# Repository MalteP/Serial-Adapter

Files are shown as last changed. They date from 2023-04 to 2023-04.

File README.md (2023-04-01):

# Serial Adapter

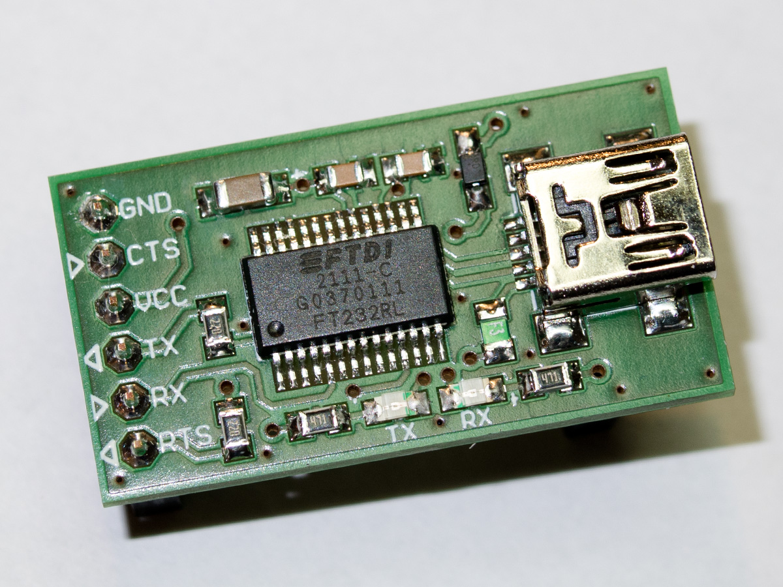
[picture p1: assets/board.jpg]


This is a modified version of the famous [Adafruit FTDI Friend](http://www.adafruit.com/products/284), which has the advantage that you can change the signal and power lines separately to be either 3.3V or 5V.

For short circuit protection a PTC fuse (200mA, 0805 package) has been added. There is also a schottky diode (SOD-323 package) in the VCC output path, protecting the USB port from reverse current flow. (Target powered while computer switched off)

It has become a very useful tool during software development on my [DIY Moteino R6](https://lowpowerlab.com/guide/diy-moteino/). While there is also an open sourced [FTDI Adapter](https://github.com/LowPowerLab/FTDIAdapter) board, it lacks of the features mentioned above when compared to the commercial revision R3.

Parts used:
- Fuse F1: 0ZCK0020FF2G (Mouser), FSMD020-0805-R (Reichelt) or equivalent
- Schottky Diode D1: CUS10F30 (Mouser), NSR0320MW2T1G (Reichelt, Mouser) or equivalent

Links:
- [Schematic (PDF)](ftdifriendsch.pdf)
- [Circuit board (Aisler)](https://aisler.net/p/BZEBBFWU)

### License

Adafruit invests time and resources providing this open source design, please support Adafruit and open-source hardware by purchasing products from [Adafruit](https://www.adafruit.com)!

Designed by Limor Fried/Ladyada for Adafruit Industries.

Creative Commons Attribution/Share-Alike, all text above must be included in any redistribution. See license.txt for additional details.

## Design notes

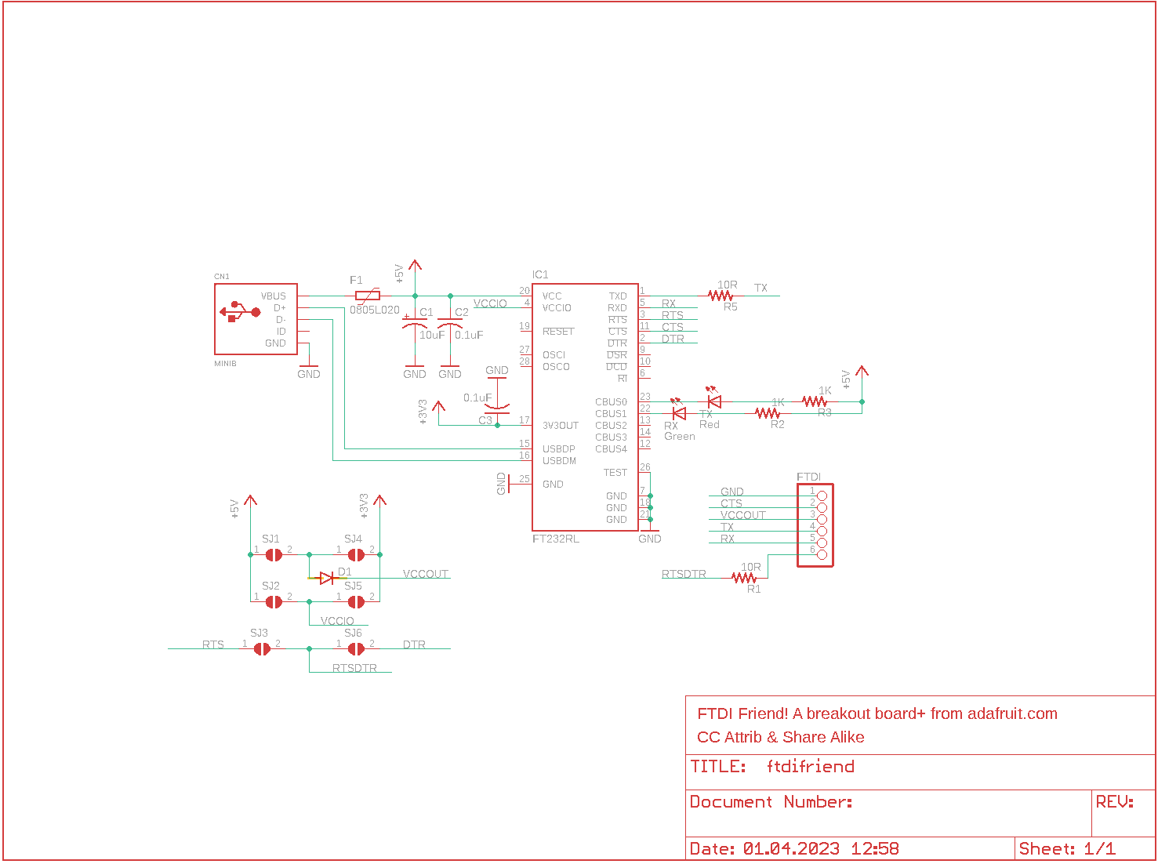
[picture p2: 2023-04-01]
ftdifriendsch.png

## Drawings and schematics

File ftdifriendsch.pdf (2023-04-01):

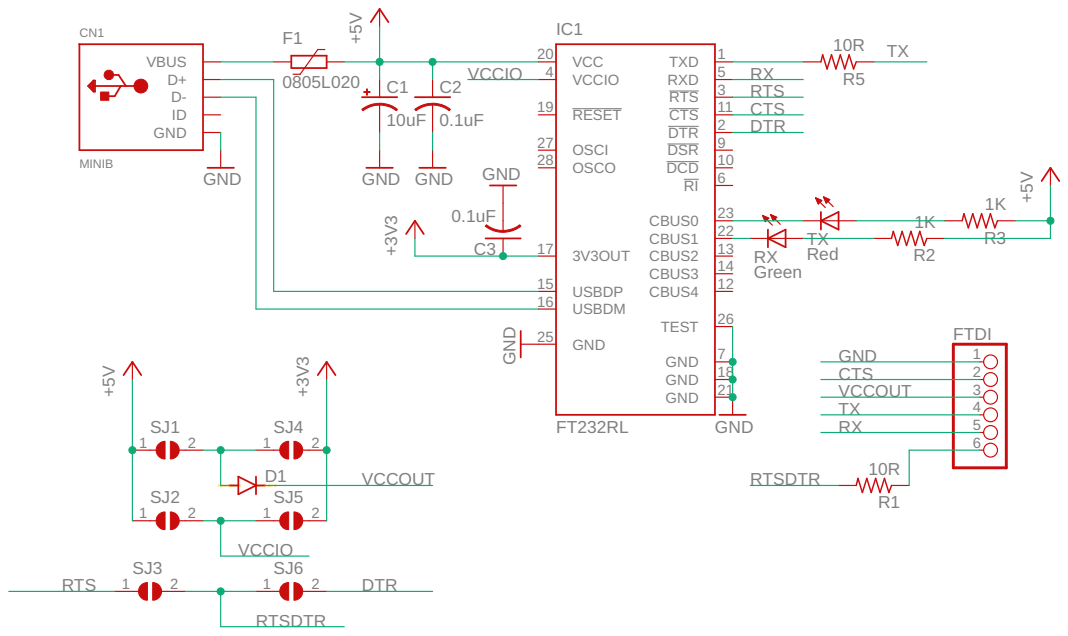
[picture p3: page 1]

FTDI Friend! A breakout board+ from adafruit.com
CC Attrib & Share Alike

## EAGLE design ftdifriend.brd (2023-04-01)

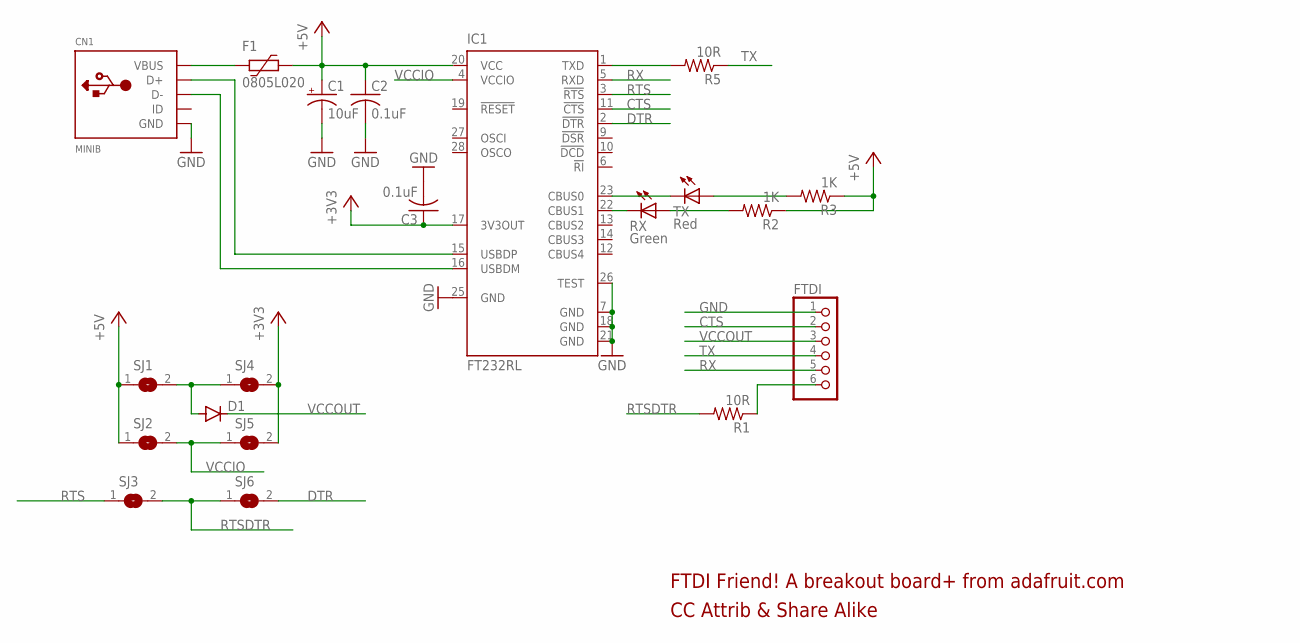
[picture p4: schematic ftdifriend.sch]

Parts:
C1: 10uF; A/3216-18R
C2, C3: 0.1uF; C0805K
CN1: MINIB; USB-MINIB
D1: CUS10F30; SOD323-W
F1: 0805L020; 0805L
FTDI: PINHD-1X6CB; 1X06-CLEANBIG
IC1: FT232RL; SSOP28
R1, R5: 10R; R0805
R2, R3: 1K; R0805
RX: Green; CHIP-LED0805
SJ1, SJ2, SJ3, SJ4, SJ5, SJ6: SJ
TX: Red; CHIP-LED0805

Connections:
+3V3: C3.1, IC1.17 (3V3OUT), SJ4.2, SJ5.2
+5V: C1.+, C2.1, F1.1, IC1.20 (VCC), R2.1, R3.1, SJ1.1, SJ2.1
CTS: FTDI.2, IC1.11 (!CTS)
D+: CN1.D+, IC1.15 (USBDP)
D-: CN1.D-, IC1.16 (USBDM)
DTR: IC1.2 (!DTR), SJ6.2
GND: C1.-, C2.2, C3.2, CN1.GND, FTDI.1, IC1.7 (GND), IC1.18 (GND), IC1.21 (GND), IC1.25 (GND), IC1.26 (TEST)
unnamed: FTDI.6, R1.1
unnamed: IC1.1 (TXD), R5.2
unnamed: IC1.23 (CBUS0), TX.C
unnamed: IC1.22 (CBUS1), RX.C
unnamed: R2.2, RX.A
unnamed: R3.2, TX.A
unnamed: CN1.VBUS, F1.2
RTS: IC1.3 (!RTS), SJ3.1
RTSDTR: R1.2, SJ3.2, SJ6.1
RX: FTDI.5, IC1.5 (RXD)
TX: FTDI.4, R5.1
VCCIO: IC1.4 (VCCIO), SJ2.2, SJ5.1
VCCOUT: D1.C, FTDI.3
VCCOUT_A: D1.A, SJ1.2, SJ4.1

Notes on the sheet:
CC Attrib & Share Alike
FTDI Friend! A breakout board+ from adafruit.com

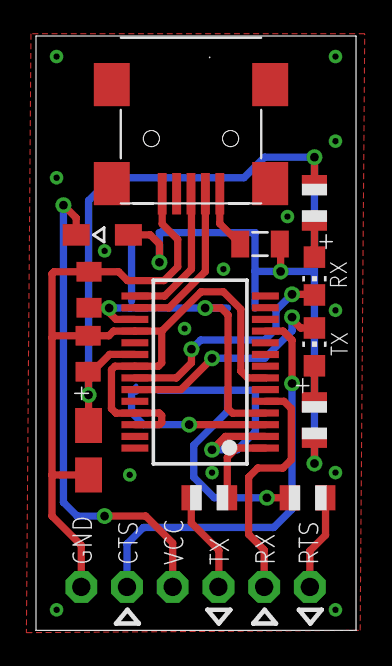
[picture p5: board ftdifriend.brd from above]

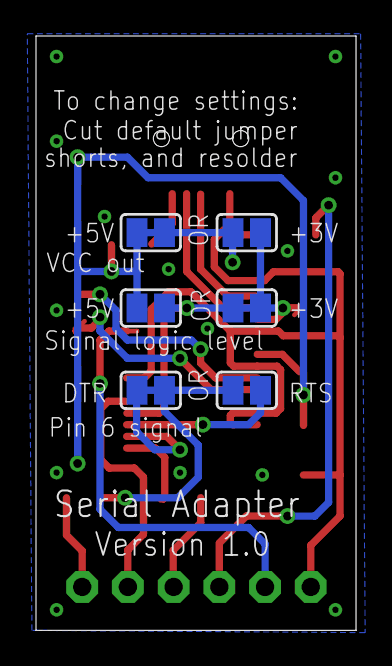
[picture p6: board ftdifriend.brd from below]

Board: 2 copper layers, 17.8 x 33.0 mm, 20 parts (6 on the bottom side), 21 nets.
